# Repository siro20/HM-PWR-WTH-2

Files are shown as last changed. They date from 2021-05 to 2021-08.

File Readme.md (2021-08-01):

# HM-PWR-WTH2

Open Source kicad Homematic Homebrew PCB for HmIP-WTH-2.

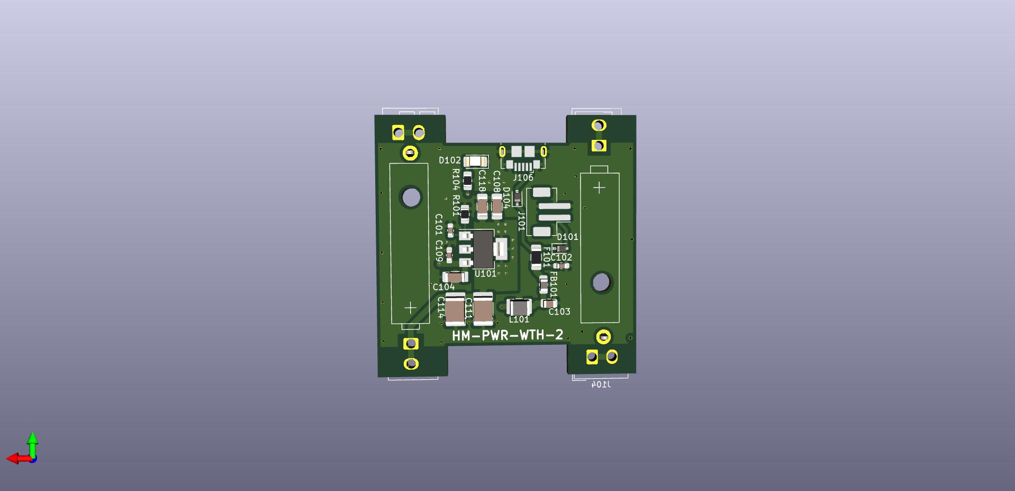
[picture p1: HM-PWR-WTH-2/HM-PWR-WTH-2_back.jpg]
PCB


The PCB supports an input voltage of 3.3V - 36V and generates 2.9V on the
battery emulator clamps. It features a micro USB connector and a JST 2pin
connector.

A LED indicates if the board is working and generates a minimum current
required for stability of the LT3080 regulator.

## Schematics

[HM-PWR-WTH-2.pdf](./HM-PWR-WTH-2/HM-PWR-WTH-2.pdf)

## Pictures

PCB back PCB
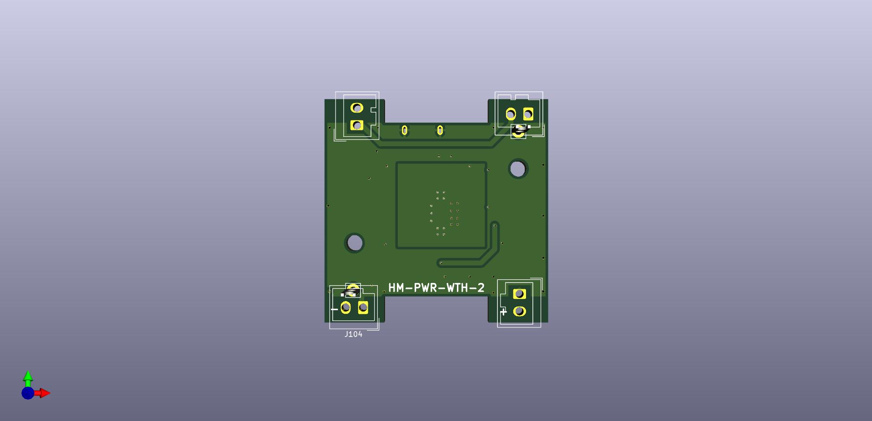
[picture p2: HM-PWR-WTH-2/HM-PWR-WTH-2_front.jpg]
PCB front PCB


** Mounting plate **

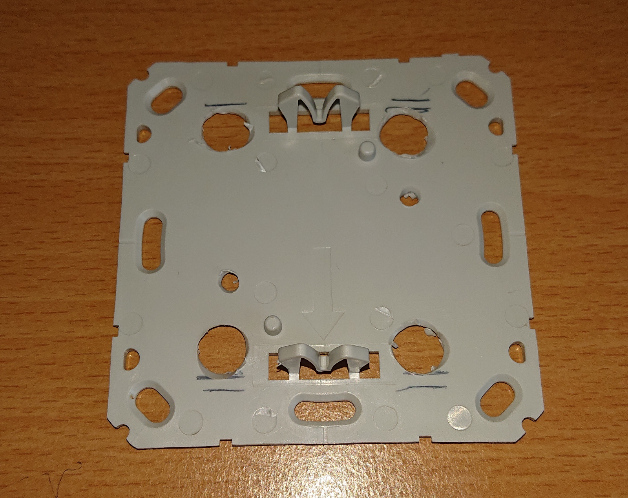
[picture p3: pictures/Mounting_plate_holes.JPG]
Drilled holes


** Assembled **

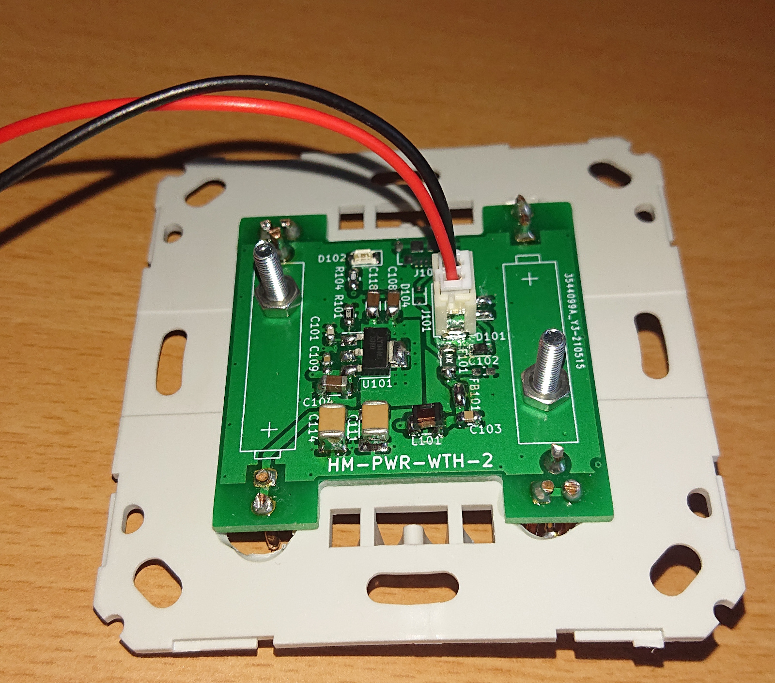
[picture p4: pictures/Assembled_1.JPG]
Assembled PCB1 Assembled

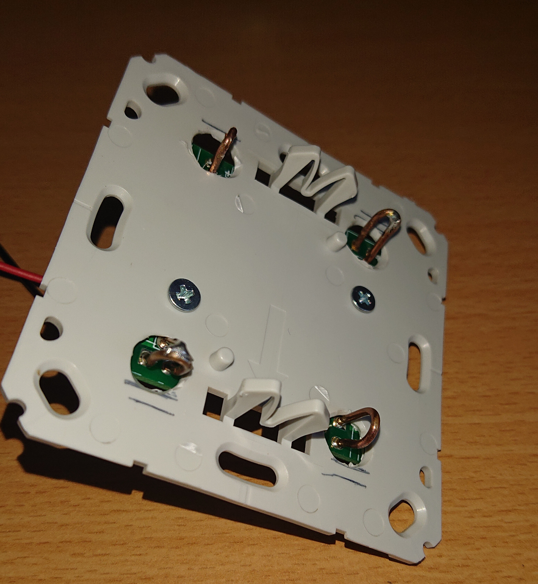
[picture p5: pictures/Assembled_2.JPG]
Assembled PCB2 Assembled


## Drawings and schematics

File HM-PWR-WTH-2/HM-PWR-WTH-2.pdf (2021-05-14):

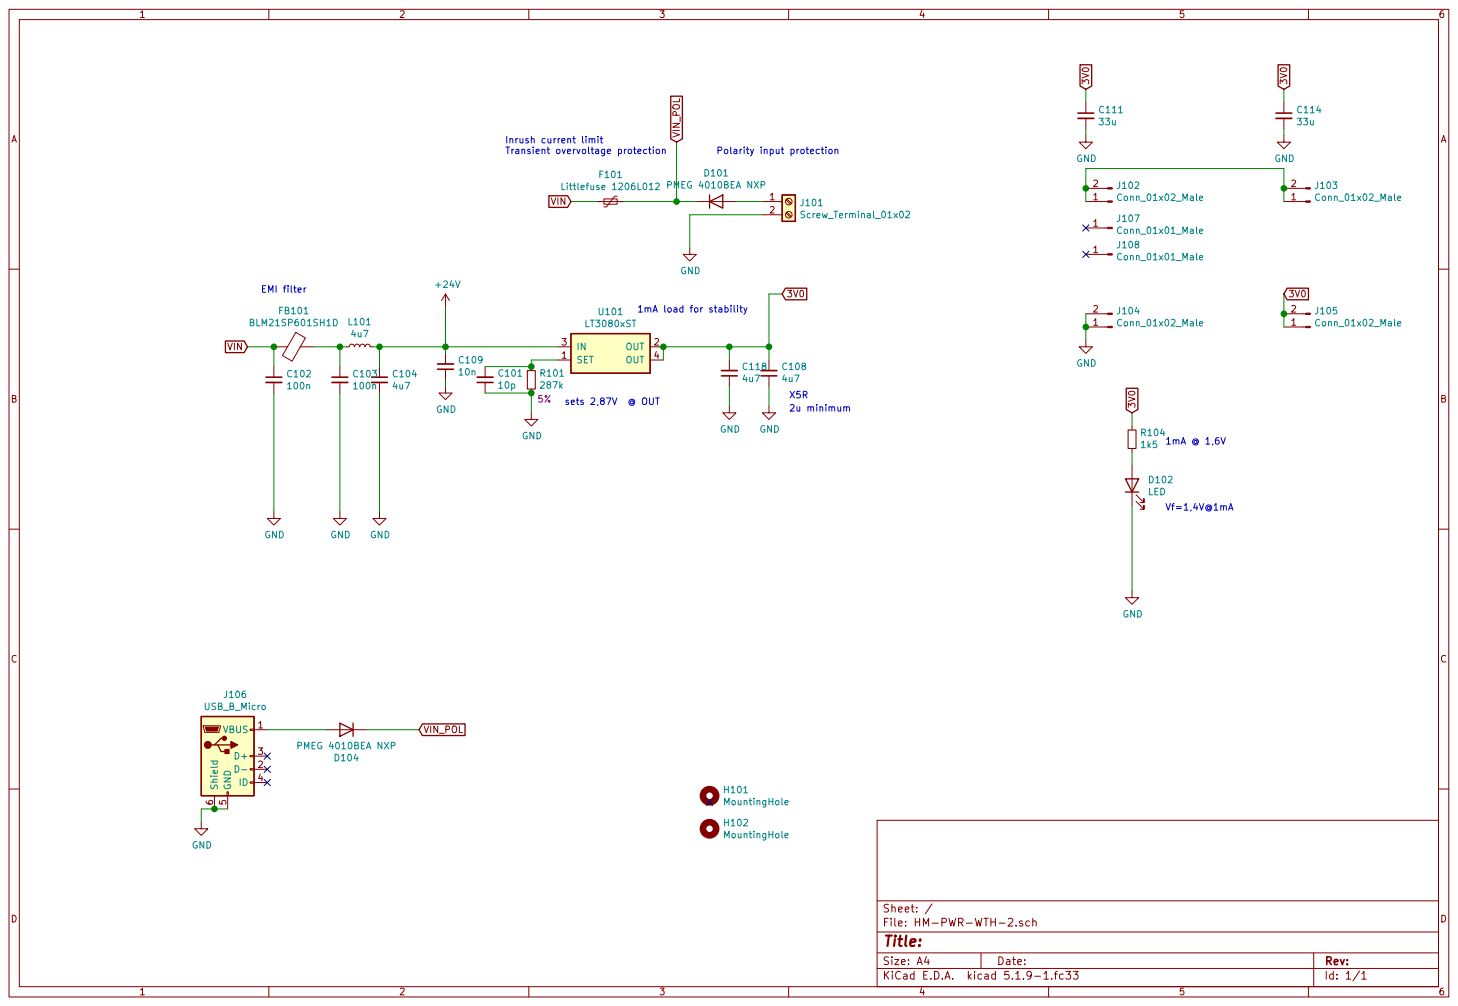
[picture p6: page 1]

Id: 1/1 Title: File: HM-PWR-WTH-2.sch Sheet: /

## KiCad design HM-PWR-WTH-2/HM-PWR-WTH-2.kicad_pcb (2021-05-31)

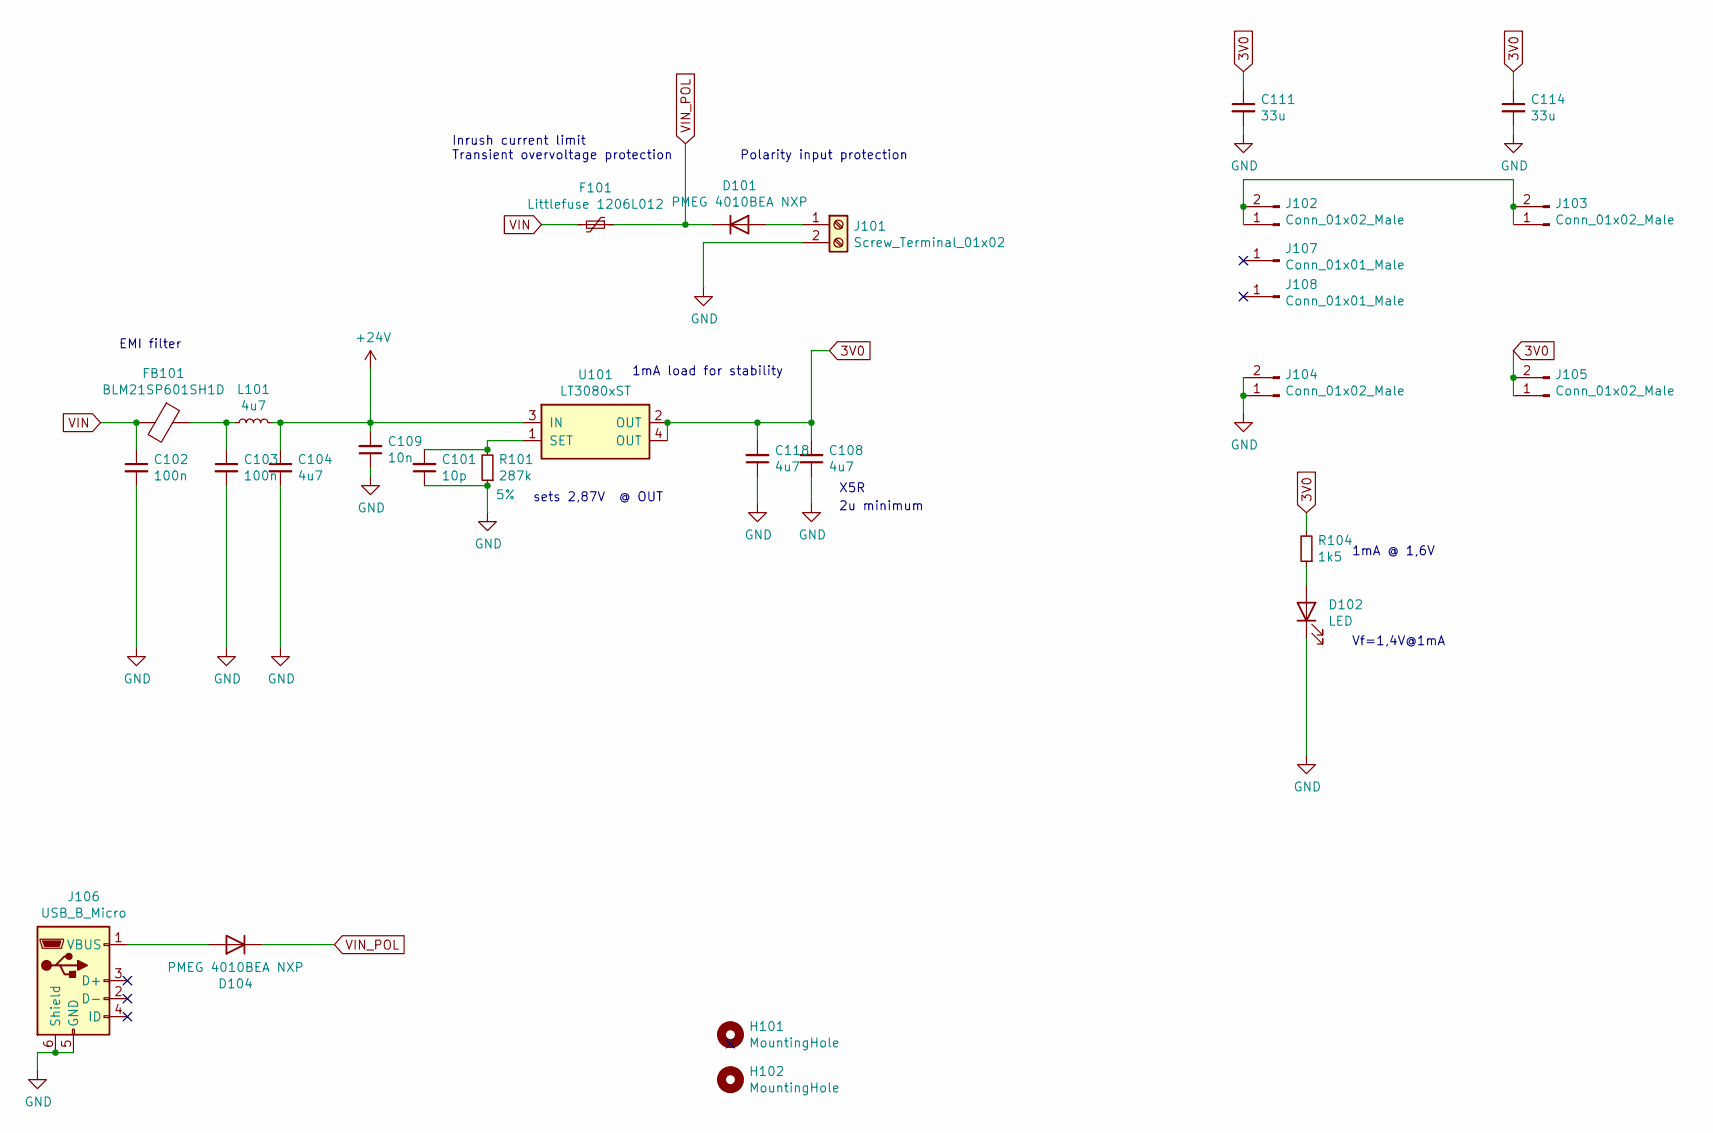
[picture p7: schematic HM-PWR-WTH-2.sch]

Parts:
C101: 10p; C_0603_1608Metric
C102: 100n; C_0603_1608Metric_Pad1.08x0.95mm_HandSolder
C103: 100n; C_0805_2012Metric
C104, C108, C118: 4u7; C_1206_3216Metric_Pad1.33x1.80mm_HandSolder
C109: 10n; C_0603_1608Metric_Pad1.08x0.95mm_HandSolder
C111, C114: 33u; C_1812_4532Metric_Pad1.57x3.40mm_HandSolder
D101, D104: PMEG 4010BEA NXP; D_SOD-323
D102: LED; LED_1206_3216Metric
F101: Littlefuse 1206L012; Fuse_1206_3216Metric_Pad1.42x1.75mm_HandSolder
FB101: BLM21SP601SH1D; L_0805_2012Metric_Pad1.15x1.40mm_HandSolder
H101: MountingHole; MountingHole_3.2mm_M3_ISO14580
H102: MountingHole; MountingHole_3.2mm_M3
J101: Screw_Terminal_01x02; JST_PH_B2B-PH-SM4-TB_1x02-1MP_P2.00mm_Vertical
J102, J103, J104, J105: Conn_01x02_Male; Wago_734-132_1x02_P3.50mm_Vertical
J106: USB_B_Micro; USB_Micro-B_GCT_USB3076-30-A
J107, J108: Conn_01x01_Male; Pin_D1.4mm_L8.5mm_W2.8mm_FlatFork
L101: 4u7; L_1210_3225Metric_Pad1.42x2.65mm_HandSolder
R101: 287k; R_0805_2012Metric_Pad1.20x1.40mm_HandSolder; Tolerance 5%
R104: 1k5; R_0805_2012Metric_Pad1.20x1.40mm_HandSolder
U101: LT3080xST; SOT-223

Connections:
3V0: C108.2, C111.1, C114.1, C118.2, J105.1, J105.2, R104.2, U101.2 (OUT), U101.4 (OUT)
+24V: C104.1, C109.2, L101.2, U101.3 (IN)
GND: C101.1, C102.2, C103.2, C104.2, C108.1, C109.1, C111.2, C114.2, C118.1, D102.1 (K), J101.2, J104.1, J104.2, J106.5 (GND), J106.6 (Shield), R101.1
unnamed: C101.2, R101.2, U101.1 (SET)
unnamed: C103.1, FB101.1, L101.1
unnamed: D101.2 (A), J101.1
unnamed: D102.2 (A), R104.1
unnamed: D104.2 (A), J106.1 (VBUS)
unnamed: J102.1, J102.2, J103.1, J103.2
VIN: C102.1, F101.2, FB101.2
VIN_POL: D101.1 (K), D104.1 (K), F101.1

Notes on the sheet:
Inrush current limit Transient overvoltage protection
Polarity input protection
EMI filter
X5R
2u minimum
1mA load for stability
sets 2,87V @ OUT
Vf=1,4V@1mA
1mA @ 1,6V

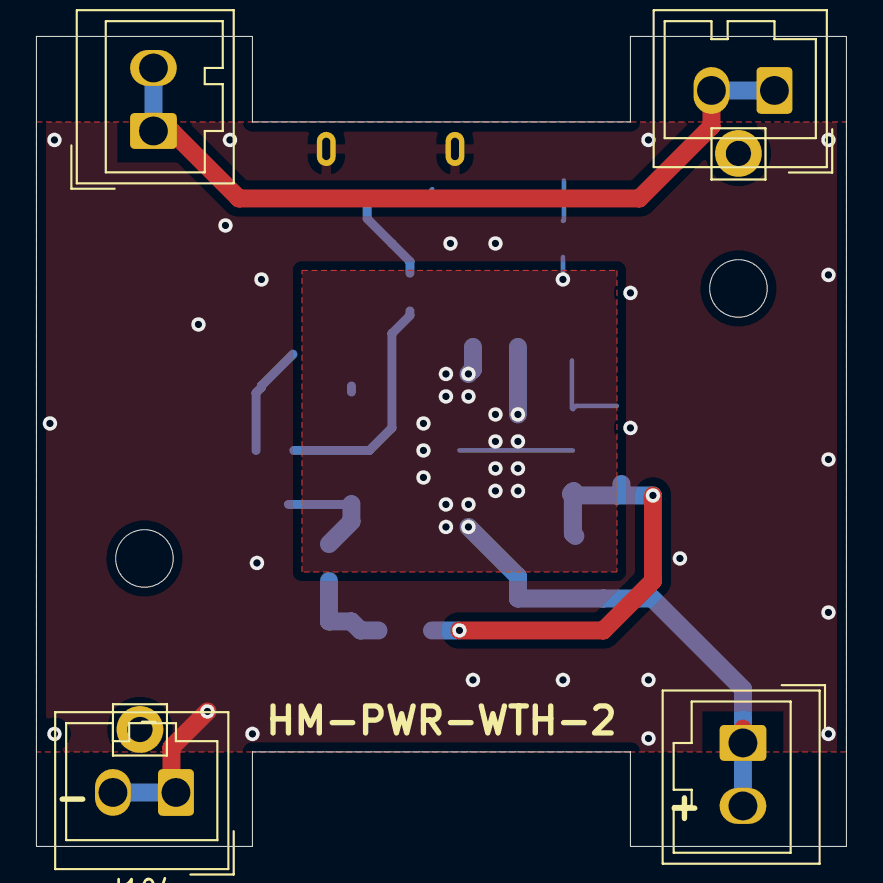
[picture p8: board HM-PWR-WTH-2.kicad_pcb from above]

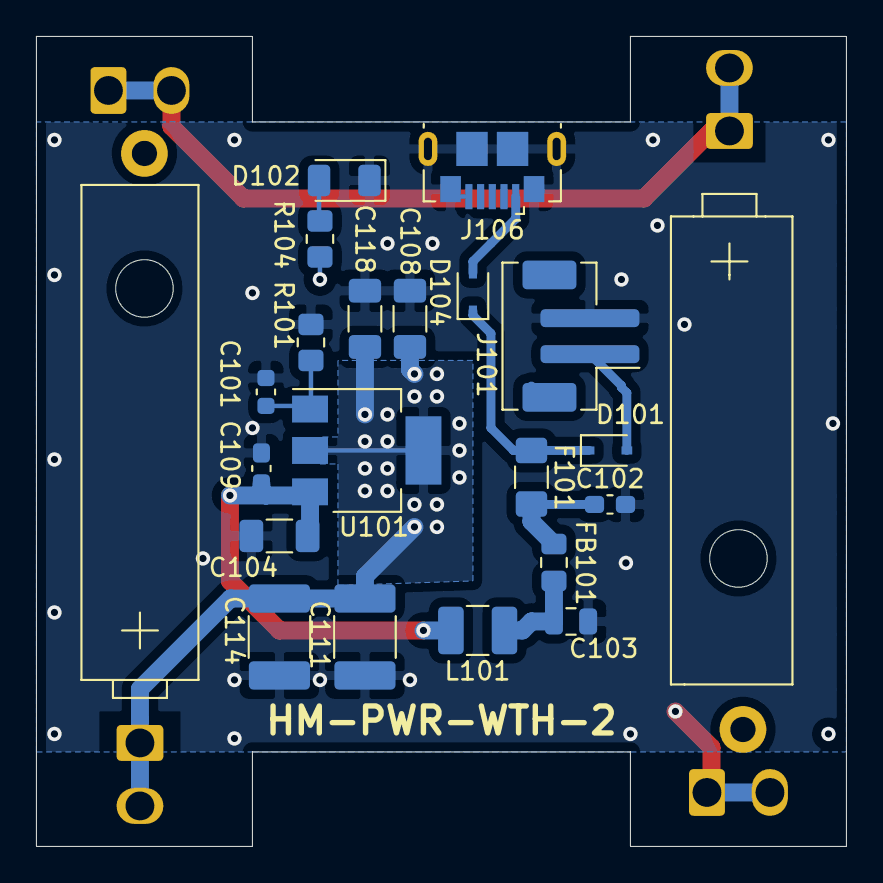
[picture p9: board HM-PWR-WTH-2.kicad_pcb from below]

Board: 2 copper layers, 45.0 x 45.0 mm, 28 parts (20 on the bottom side), 11 nets.

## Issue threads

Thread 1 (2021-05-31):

Part change: Diode packages are too small

PatrickRudolph, 2021-05-31:
Replace D101 / D104 SOD323 with a bigger package to make soldering easier.

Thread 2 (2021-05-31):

Part change: LED current

PatrickRudolph, 2021-05-31:
The LED ```RND 135-00188 - SMD-LED Rot 632nm 1206 115mcd 25mA``` has a Vf of 1,75V @ 0,8mA.
Change R104 to 1k2 when using *RND 135-00188*

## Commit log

2021-04-18 HM-PWR-WTH-2: Switch to TPS70930
    [HM-PWR-WTH-2.kicad_pcb, HM-PWR-WTH-2.sch]
2021-04-18 HM-PWR-WTH-2: Add schmatic and PCB view
2021-05-11 Redesign board
    - Replace regulator with one easier to get in germany
    - Add LED for minimum current draw of 1mA
    - Swap battery + and -
    [HM-PWR-WTH-2.kicad_pcb, HM-PWR-WTH-2.sch]
2021-05-14 Redesign board
    - Move all parts to middle and back
    - Use less capacitors
    - Add mounting holes
    - Add battery symbols
    [HM-PWR-WTH-2.kicad_pcb, HM-PWR-WTH-2.sch]
2021-05-31 Update PCB layout
    [HM-PWR-WTH-2.kicad_pcb]
